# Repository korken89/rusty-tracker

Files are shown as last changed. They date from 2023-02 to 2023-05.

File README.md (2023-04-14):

# Rusty Tracker

**A learning board for LTE-M and tracking technologies**

## Versions

There are 2 versions of the board, based on:

1. uBlox R422-M10S
2. nRF9160 + uBlox M10S GNSS

which can be found in the `master` branch and `nrf` branch respectively.

The two IFA antennas are simulated with Ansys HFSS, files are available.

### uBlox R422-M10S version

This is the main board that development is happening for in the `firmware` folder.

The hardware is tested and working.

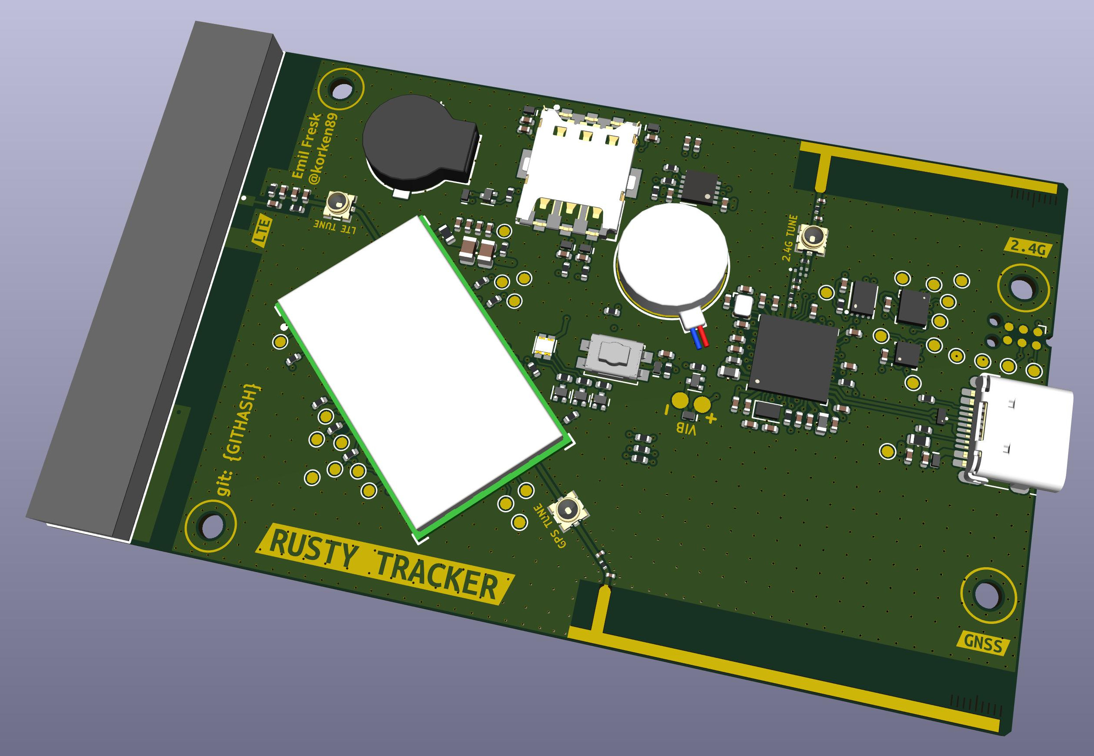
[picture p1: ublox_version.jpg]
ublox uBlox version


### nRF9160 version

This was made as well for learning, not manufactured nor tested.

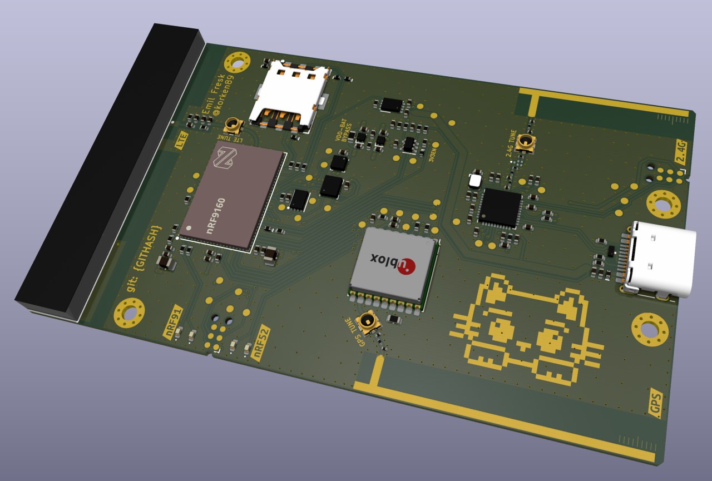
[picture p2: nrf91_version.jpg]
nrf9160 nRf9160 version


## License

This work is licensed under [CERN-OHL-P](cern_ohl_p_v2.txt).

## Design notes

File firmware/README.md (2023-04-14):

# Rusty Tracker Firmware

Firmware for the Rusty Tracker board.

## License

Licensed under either of

- Apache License, Version 2.0 ([LICENSE-APACHE](LICENSE-APACHE) or
  http://www.apache.org/licenses/LICENSE-2.0)

- MIT license ([LICENSE-MIT](LICENSE-MIT) or http://opensource.org/licenses/MIT)

at your option.

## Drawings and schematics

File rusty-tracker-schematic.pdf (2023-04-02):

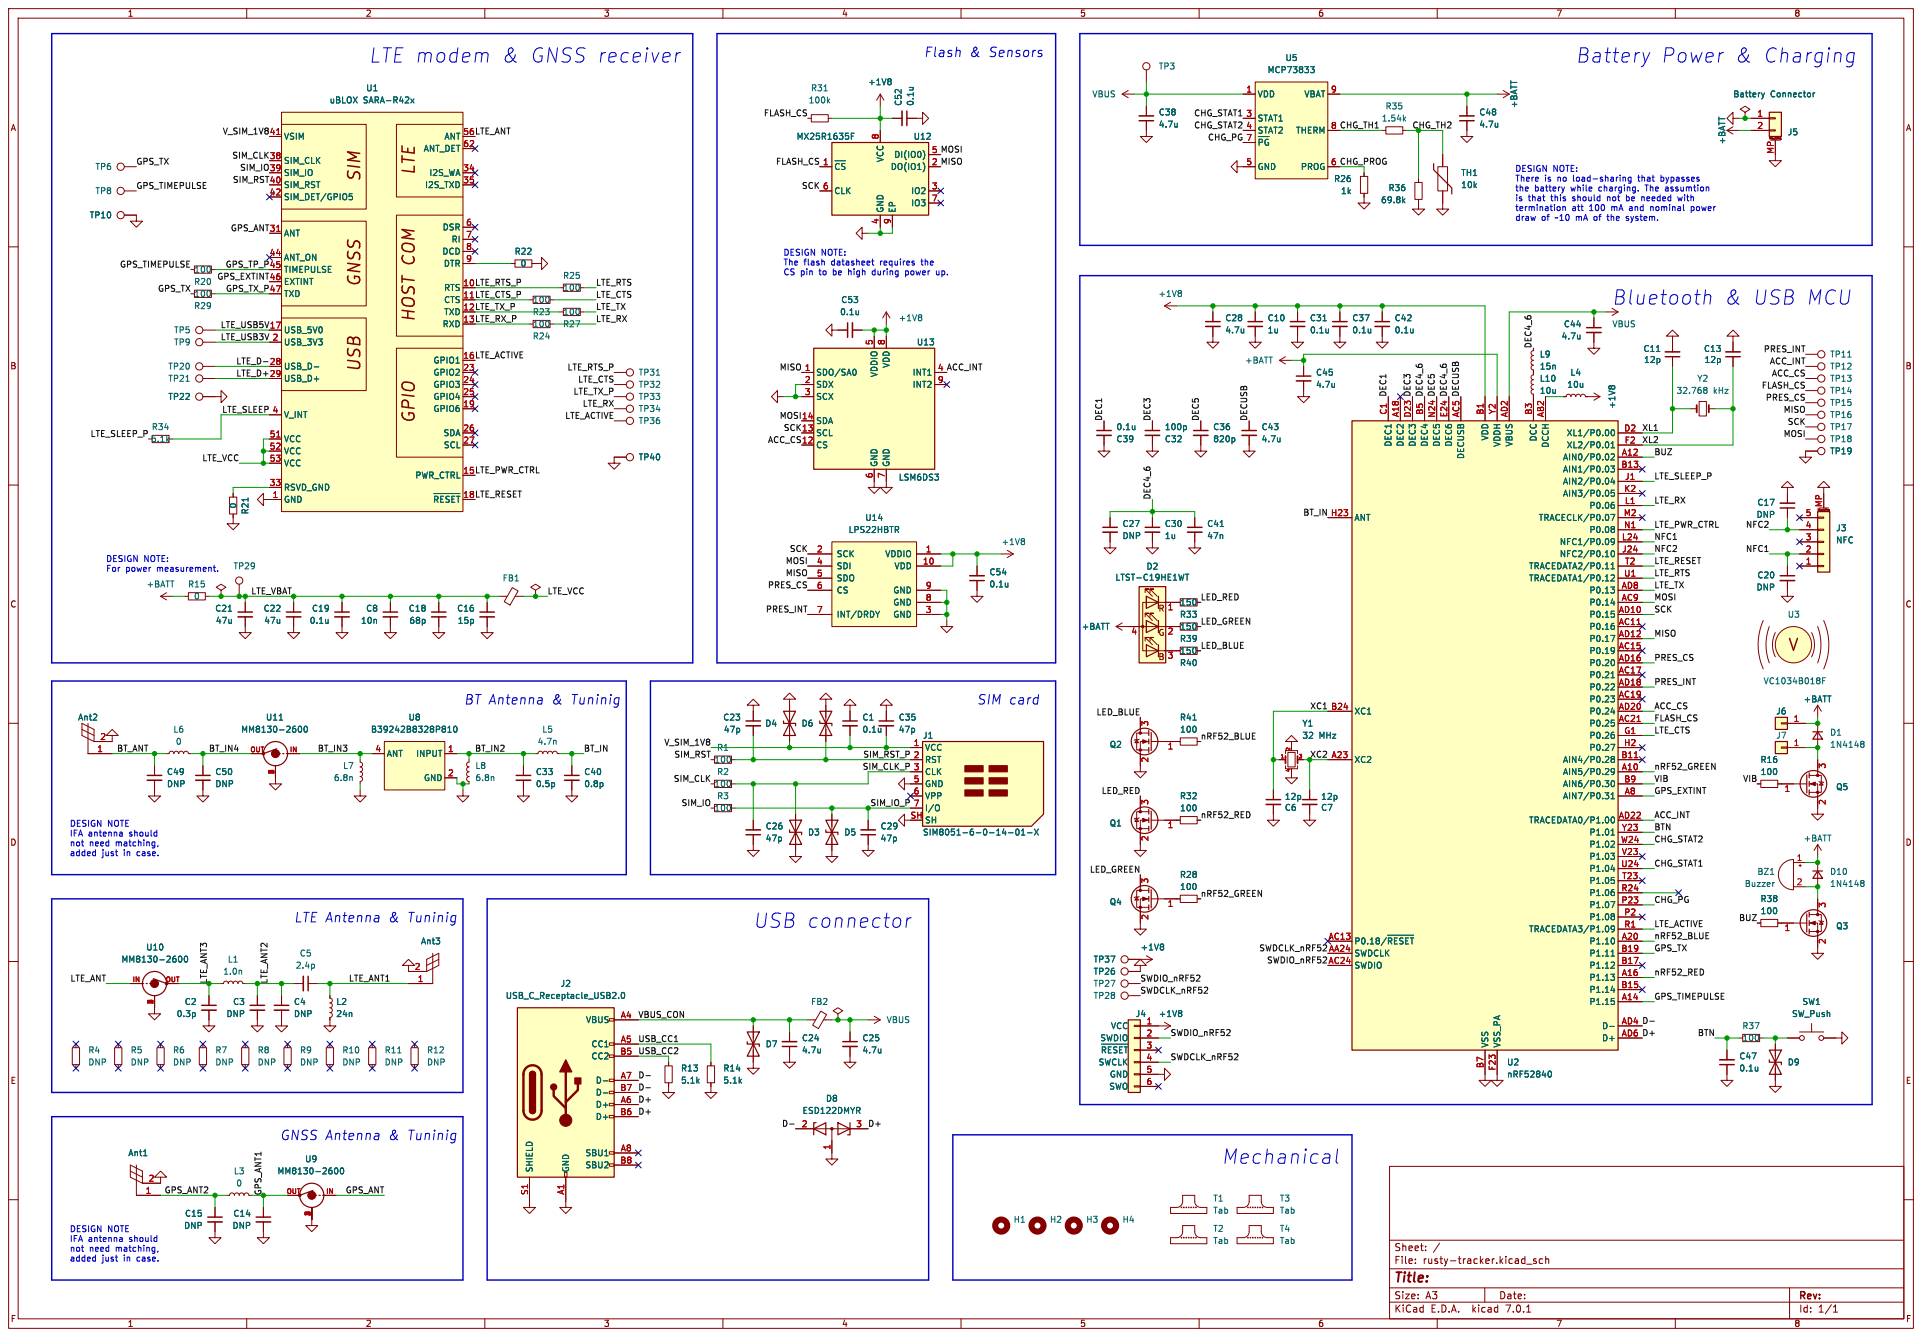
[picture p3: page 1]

LTE modem & GNSS receiver

is that this should not be needed with

SIM card
VCC 1 RST 2 CLK 3 GND 5 VPP 6

INPUT 1 GND 2 ANT 4 C15 DNP

IFA antenna should
not need matching, added just in case.

Id: 1/1 Title: File: rusty-tracker.kicad_sch Sheet: /

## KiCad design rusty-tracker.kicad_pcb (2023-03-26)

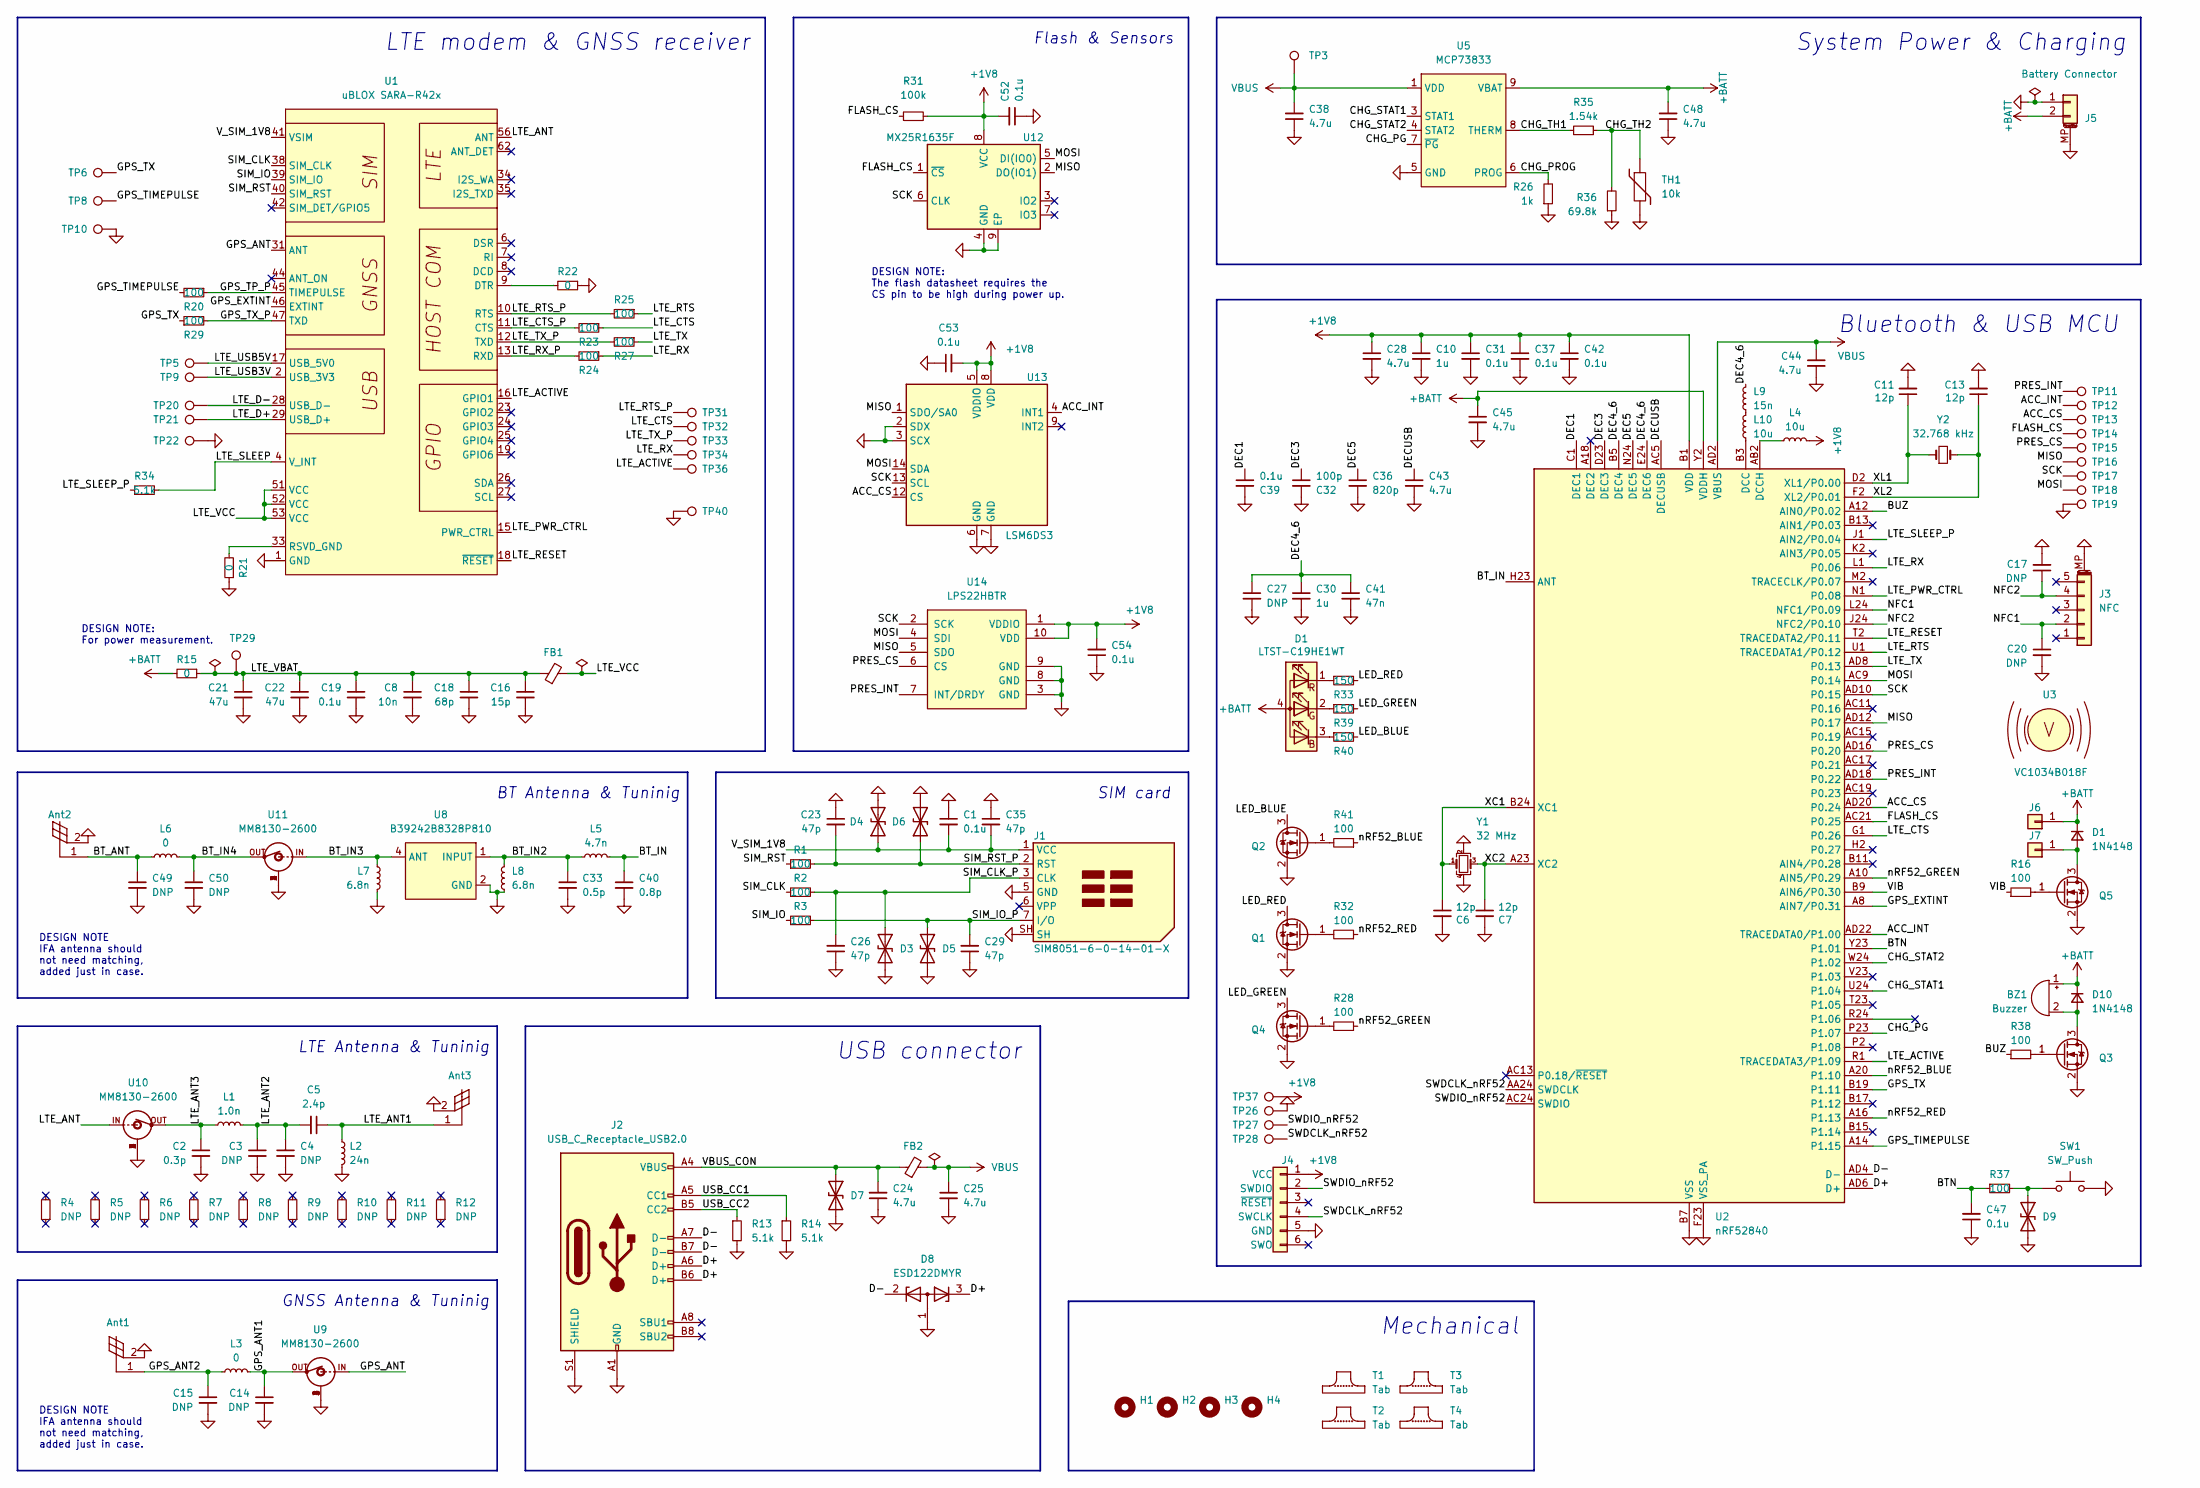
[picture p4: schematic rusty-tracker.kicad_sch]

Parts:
Ant1: antenna; gps-inverted-f
Ant2: antenna; 2.4ghz-inverted-f
Ant3: antenna; P822602
BZ1: Buzzer; AST0927
C1, C19, C31, C37, C39, C42, C47, C52, C53, C54: 0.1u; C_0402
C2: 0.3p; C_0402
C3, C4, C17, C20, C27: DNP; C_0402
C5: 2.4p; C_0402
C6, C7: 12p; C_0402; Tolerance 1%
C8: 10n; C_0402
C10, C30: 1u; C_0402
C11, C13: 12p; C_0402
C14, C15, C49, C50: DNP; C_0201
C16: 15p; C_0402
C18: 68p; C_0402
C21, C22: 47u; C_0805
C23, C26, C29, C35: 47p; C_0402
C24, C25, C28, C38, C43, C44, C45, C48: 4.7u; C_0402
C32: 100p; C_0402
C33: 0.5p; C_0201
C36: 820p; C_0402
C40: 0.8p; C_0201
C41: 47n; C_0402
D1, D10: 1N4148; D_0402_DFN1006
D3, D4, D5, D6, D7, D9: D_TVS; D_0402_DFN1006
D8: ESD122DMYR; X2SON
FB1, FB2: BLM18EG221SN1D; R_0603
H1, H2, H3, H4: MountingHole_Pad; MountingHole_2.2mm_M2
J1: SIM8051-6-0-14-01-X
J2: USB_C_Receptacle_USB2.0; USB_C_Receptacle_USB4105
J3: NFC; TE_0-1734839-5_1x05-1MP_P0.5mm_Horizontal
J4: tag-connect-swd; Tag-Connect_TC2030-IDC-NL_2x03_P1.27mm_Vertical
J5: Battery Connector; JST_SH_SM02B-SRSS-TB_1x02-1MP_P1.00mm_Horizontal
J6, J7: Conn_01x01; pad_circ_1.5mm
L1: 1.0n; R_0402
L2: 24n; R_0402
L3, L6: 0; R_0201
L4, L10: 10u; R_0603
L5: 4.7n; R_0201
L7, L8: 6.8n; R_0201
L9: 15n; R_0402
Q1, Q2, Q3, Q4, Q5: RUM002N02T2L; SOT-723
R1, R2, R3, R16, R20, R23, R24, R25, R27, R28, R29, R32, R37, R38, R41: 100; R_0402
R4, R5, R6, R7, R8, R9, R10, R11, R12: DNP; ANT_0402
R13, R14, R34: 5.1k; R_0402
R15, R21, R22: 0; R_0402
R26: 1k; R_0402
R31: 100k; R_0402
R33, R39, R40: 150; R_0402
R35: 1.54k; R_0402
R36: 69.8k; R_0402
SW1: SW_Push; SW_SPST_EVQP2
T1, T2, T3, T4: Tab
TH1: 10k; R_0402
TP3, TP5, TP6, TP8, TP9, TP10, TP11, TP12, TP13, TP14, TP15, TP16, TP17, TP18, TP19, TP20, TP21, TP22, TP26, TP27, TP28, TP29, TP31, TP32, TP33, TP34, TP36, TP37, TP40: TestPoint; TestPoint_Pad_D1.0mm
U1: uBLOX SARA-R42x; u-blox SARA-R4
U2: nRF52840; Nordic_AQFN-73-1EP_7x7mm_P0.5mm
U3: VC1034B018F
U5: MCP73833; DFN-10-1EP_3x3mm_P0.5mm_EP1.55x2.48mm
U8: B39242B8328P810
U9, U10, U11: MM8130-2600
U12: MX25R1635F; USON-8-3x2mm-EP
U13: LSM6DS3; LGA-14_3x2.5mm_P0.5mm_LayoutBorder3x4y
U14: LPS22HBTR; ST_HLGA-10_2x2mm_P0.5mm_LayoutBorder3x2y
Y1: 32 MHz; Crystal_4Pin_2.0x1.6mm
Y2: 32.768 kHz; Crystal_SMD_2012-2Pin_2.0x1.2mm

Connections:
+1V8: C10.1, C28.1, C31.1, C37.1, C42.1, C52.2, C53.2, C54.2, J4.1 (VCC), L4.1, R31.2, TP37.1, U2.A22 (VDD), U2.AD14 (VDD), U2.AD23 (VDD), U2.B1 (VDD), U2.W1 (VDD), U12.8 (VCC), U13.5 (VDDIO), U13.8 (VDD), U14.1 (VDDIO), U14.10 (VDD)
/ACC_CS: TP13.1, U2.AD20 (P0.24), U13.12 (CS)
/ACC_INT: TP12.1, U2.AD22 (TRACEDATA0/P1.00), U13.4 (INT1)
/BTN: C47.2, R37.1, U2.Y23 (P1.01)
/BT_ANT: Ant2.1, C49.1, L6.2
/BT_IN: C40.1, L5.1, U2.H23 (ANT)
/BT_IN2: C33.1, L5.2, L8.1, U8.1 (INPUT)
/BT_IN3: L7.2, U8.4 (ANT), U11.IN
/BT_IN4: C50.1, L6.1, U11.OUT
/BUZ: R38.1, U2.A12 (AIN0/P0.02)
/CHG_PG: U2.P23 (P1.07), U5.7 (~PG)
/CHG_PROG: R26.2, U5.6 (PROG)
/CHG_STAT1: U2.U24 (P1.04), U5.3 (STAT1)
/CHG_STAT2: U2.W24 (P1.02), U5.4 (STAT2)
/CHG_TH1: R35.2, U5.8 (THERM)
/CHG_TH2: R35.1, R36.2, TH1.1
/D+: D8.3 (K), J2.A6 (D+), J2.B6 (D+), U2.AD6 (D+)
/D-: D8.2 (K), J2.A7 (D-), J2.B7 (D-), U2.AD4 (D-)
/DEC1: C39.1, U2.C1 (DEC1)
/DEC3: C32.1, U2.D23 (DEC3)
/DEC4_6: C27.1, C30.1, C41.1, L9.1, U2.B5 (DEC4), U2.E24 (DEC6)
/DEC5: C36.1, U2.N24 (DEC5)
/DECUSB: C43.1, U2.AC5 (DECUSB)
/FLASH_CS: R31.1, TP14.1, U2.AC21 (P0.25), U12.1 (~CS)
/GPS_ANT: U1.31 (ANT), U9.IN
/GPS_ANT1: C14.1, L3.2, U9.OUT
/GPS_ANT2: Ant1.1, C15.1, L3.1
/GPS_EXTINT: U1.46 (EXTINT), U2.A8 (AIN7/P0.31)
/GPS_TIMEPULSE: R20.2, TP8.1, U2.A14 (P1.15)
/GPS_TP_P: R20.1, U1.45 (TIMEPULSE)
/GPS_TX: R29.1, TP6.1, U2.B19 (P1.11)
/GPS_TX_P: R29.2, U1.47 (TXD)
/LED_BLUE: Q2.3 (D), R40.2
/LED_GREEN: Q4.3 (D), R39.2
/LED_RED: Q1.3 (D), R33.2
/LTE_ACTIVE: TP36.1, U1.16 (GPIO1), U2.R1 (TRACEDATA3/P1.09)
/LTE_ANT: U1.56 (ANT), U10.IN
/LTE_ANT1: Ant3.1, C5.1, L2.1
/LTE_ANT2: C3.1, C4.1, C5.2, L1.2
/LTE_ANT3: C2.1, L1.1, U10.OUT
/LTE_CTS: R23.1, TP32.1, U2.G1 (P0.26)
/LTE_CTS_P: R23.2, U1.11 (CTS)
/LTE_D+: TP21.1, U1.29 (USB_D+)
/LTE_D-: TP20.1, U1.28 (USB_D-)
/LTE_PWR_CTRL: U1.15 (PWR_CTRL), U2.N1 (P0.08)
/LTE_RESET: U1.18 (~RESET), U2.T2 (TRACEDATA2/P0.11)
/LTE_RTS: R25.1, U2.U1 (TRACEDATA1/P0.12)
/LTE_RTS_P: R25.2, TP31.1, U1.10 (RTS)
/LTE_RX: R24.1, TP34.1, U2.L1 (P0.06)
/LTE_RX_P: R24.2, U1.13 (RXD)
/LTE_SLEEP: R34.2, U1.4 (V_INT)
/LTE_SLEEP_P: R34.1, U2.J1 (AIN2/P0.04)
/LTE_TX: R27.1, U2.AD8 (P0.13)
/LTE_TX_P: R27.2, TP33.1, U1.12 (TXD)
/LTE_USB3V: TP9.1, U1.2 (USB_3V3)
/LTE_USB5V: TP5.1, U1.17 (USB_5V0)
/LTE_VBAT: C8.1, C16.1, C18.1, C19.1, C21.1, C22.1, FB1.1, R15.1, TP29.1
/LTE_VCC: FB1.2, U1.51 (VCC), U1.52 (VCC), U1.53 (VCC)
/MISO: TP16.1, U2.AD12 (P0.17), U12.2 (DO(IO1)), U13.1 (SDO/SA0), U14.5 (SDO)
/MOSI: TP18.1, U2.AC9 (P0.14), U12.5 (DI(IO0)), U13.14 (SDA), U14.4 (SDI)
/NFC1: C20.1, J3.2, U2.L24 (NFC1/P0.09)
/NFC2: C17.1, J3.4, U2.J24 (NFC2/P0.10)
/PRES_CS: TP15.1, U2.AD16 (P0.20), U14.6 (CS)
/PRES_INT: TP11.1, U2.AD18 (P0.22), U14.7 (INT/DRDY)
/SCK: TP17.1, U2.AD10 (P0.15), U12.6 (CLK), U13.13 (SCL), U14.2 (SCK)
/SIM_CLK: R2.1, U1.38 (SIM_CLK)
/SIM_CLK_P: C26.2, D3.1 (A1), J1.3 (CLK), R2.2
/SIM_IO: R3.1, U1.39 (SIM_IO)
/SIM_IO_P: C29.2, D5.1 (A1), J1.7 (I/O), R3.2
/SIM_RST: R1.1, U1.40 (SIM_RST)
/SIM_RST_P: C23.2, D6.1 (A1), J1.2 (RST), R1.2
/SWDCLK_nRF52: J4.4 (SWCLK), TP28.1, U2.AA24 (SWDCLK)
/SWDIO_nRF52: J4.2 (SWDIO), TP27.1, U2.AC24 (SWDIO)
/USB_CC1: J2.A5 (CC1), R14.1
/USB_CC2: J2.B5 (CC2), R13.1
/VBUS_CON: C24.2, D7.1 (A1), FB2.1, J2.A4 (VBUS), J2.A9 (VBUS), J2.B4 (VBUS), J2.B9 (VBUS)
/VIB: R16.1, U2.B9 (AIN6/P0.30)
/V_SIM_1V8: C1.2, C35.2, D4.1 (A1), J1.1 (VCC), U1.41 (VSIM)
/XC1: C6.1, U2.B24 (XC1), Y1.1
/XC2: C7.1, U2.A23 (XC2), Y1.3
/XL1: C11.1, U2.D2 (XL1/P0.00), Y2.1
/XL2: C13.1, U2.F2 (XL2/P0.01), Y2.2
/nRF52_BLUE: R41.1, U2.A20 (P1.10)
/nRF52_GREEN: R28.1, U2.A10 (AIN5/P0.29)
/nRF52_RED: R32.1, U2.A16 (P1.13)
GND: Ant1.2, Ant2.2, Ant3.2, C1.1, C2.2, C3.2, C4.2, C6.2, C7.2, C8.2, C10.2, C11.2, C13.2, C14.2, C15.2, C16.2, C17.2, C18.2, C19.2, C20.2, C21.2, C22.2, C23.1, C24.1, C25.2, C26.1, C27.2, C28.2, C29.1, C30.2, C31.2, C32.2, C33.2, C35.1, C36.2, C37.2, C38.1, C39.2, C40.2, C41.2, C42.2, C43.2, C44.2, C45.2, C47.1, C48.1, C49.2, C50.2, C52.1, C53.1, C54.1, D3.2 (A2), D4.2 (A2), D5.2 (A2), D6.2 (A2), D7.2 (A2), D8.1 (A), D9.2 (A2), J1.5 (GND), J1.SH, J2.A1 (GND), J2.A12 (GND), J2.B1 (GND), J2.B12 (GND), J2.S1 (SHIELD), J3.MP (MountPin), J4.5 (GND), J5.1, J5.MP (MountPin), L2.2, L7.1, L8.2, Q1.2 (S), Q2.2 (S), Q3.2 (S), Q4.2 (S), Q5.2 (S), R13.2, R14.2, R21.1, R22.1, R26.1, R36.1, SW1.2, TH1.2, TP10.1, TP19.1, TP22.1, TP26.1, TP40.1, U1.1 (GND), U1.3 (GND), U1.5 (GND), U1.14 (GND), U1.20 (GND), U1.21 (GND), U1.22 (GND), U1.30 (GND), U1.32 (GND), U1.43 (GND), U1.50 (GND), U1.54 (GND), U1.55 (GND), U1.57 (GND), U1.58 (GND), U1.59 (GND), U1.60 (GND), U1.61 (GND), U1.63 (GND), U1.64 (GND), U1.65 (GND), U1.66 (GND), U1.67 (GND), U1.68 (GND), U1.69 (GND), U1.70 (GND), U1.71 (GND), U1.72 (GND), U1.73 (GND), U1.74 (GND), U1.75 (GND), U1.76 (GND), U1.77 (GND), U1.78 (GND), U1.79 (GND), U1.80 (GND), U1.81 (GND), U1.82 (GND), U1.83 (GND), U1.84 (GND), U1.85 (GND), U1.86 (GND), U1.87 (GND), U1.88 (GND), U1.89 (GND), U1.90 (GND), U1.91 (GND), U1.92 (GND), U1.93 (GND), U1.94 (GND), U1.95 (GND), U1.96 (GND), U2.B7 (VSS), U2.EP (VSS), U2.F23 (VSS_PA), U5.5 (GND), U5.11 (PAD), U8.2 (GND), U8.3 (GND), U8.5 (GND), U9.1, U9.2, U9.3, U9.4, U10.1, U10.2, U10.3, U10.4, U11.1, U11.2, U11.3, U11.4, U12.4 (GND), U12.9 (EP), U13.2 (SDX), U13.3 (SCX), U13.6 (GND), U13.7 (GND), U14.3 (GND), U14.8 (GND), U14.9 (GND), Y1.2, Y1.4
unnamed: BZ1.2 (+), D10.2 (A), Q3.3 (D)
unnamed: D9.1 (A1), R37.2, SW1.1
unnamed: L9.2, L10.1
unnamed: Q1.1 (G), R32.2
unnamed: Q2.1 (G), R41.2
unnamed: Q3.1 (G), R38.2
unnamed: Q4.1 (G), R28.2
unnamed: Q5.1 (G), R16.2
unnamed: R22.2, U1.9 (DTR)
unnamed: R21.2, U1.33 (RSVD_GND)
unnamed: L10.2, U2.B3 (DCC)
unnamed: L4.2, U2.AB2 (DCCH)
VBUS: C25.1, C38.2, C44.1, FB2.2, TP3.1, U2.AD2 (VBUS), U5.1 (VDD), U5.2 (VDD)

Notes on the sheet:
DESIGN NOTE IFA antenna should not need matching, added just in case.
GNSS Antenna & Tuninig
System Power & Charging
LTE modem & GNSS receiver
SIM card
LTE Antenna & Tuninig
DESIGN NOTE: The flash datasheet requires the CS pin to be high during power up.
BT Antenna & Tuninig
DESIGN NOTE: For power measurement.
Bluetooth & USB MCU
USB connector
Mechanical
Flash & Sensors

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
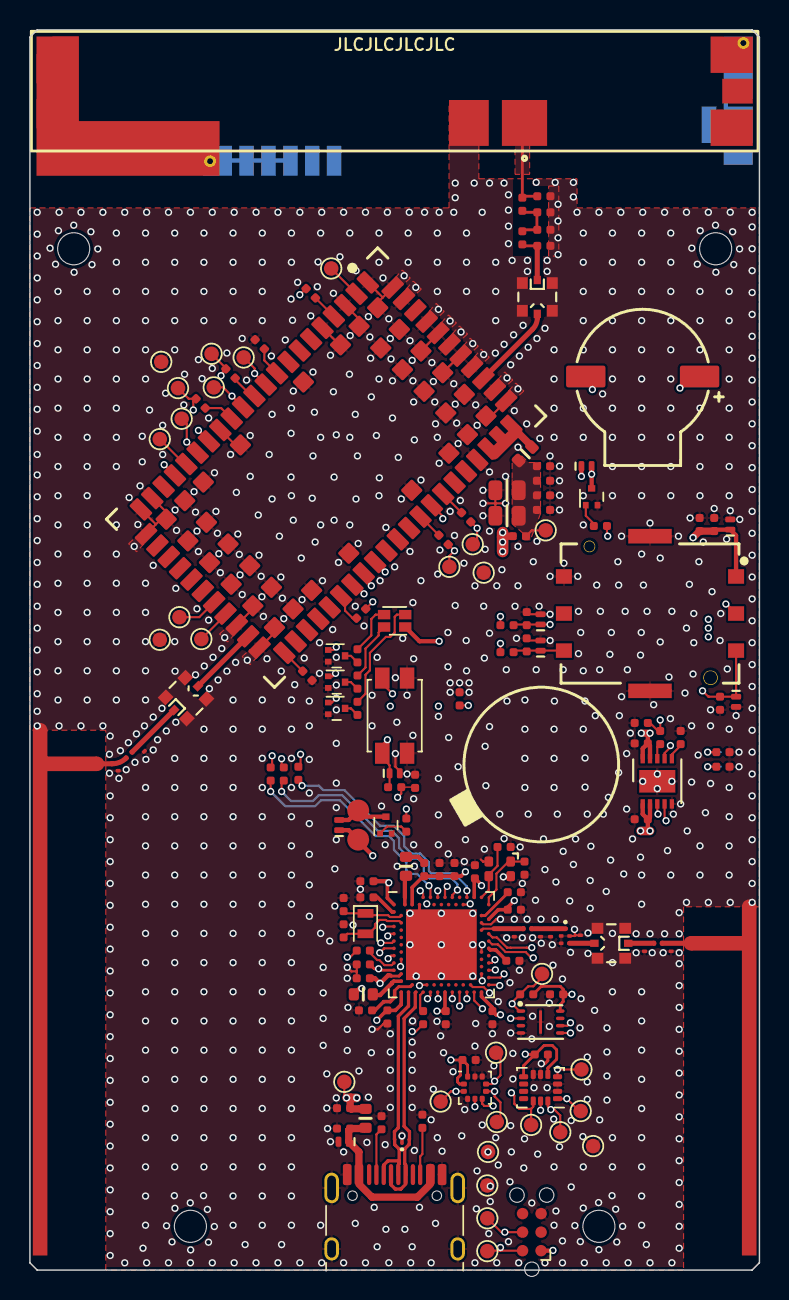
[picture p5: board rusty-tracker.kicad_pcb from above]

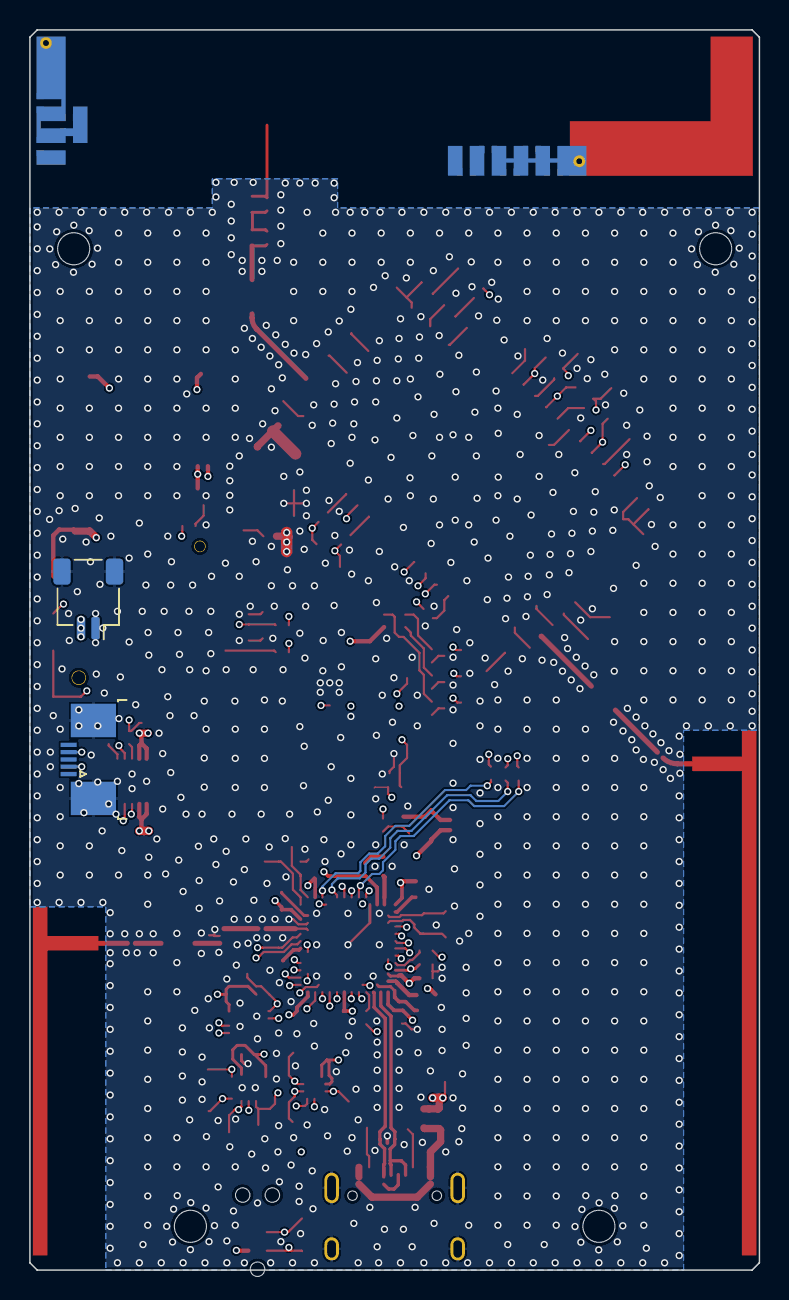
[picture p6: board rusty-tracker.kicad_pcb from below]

Board: 6 copper layers, 50.0 x 85.0 mm, 181 parts (12 on the bottom side), 104 nets.

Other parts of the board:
D2: LTST-C19HE1WT; LED_LiteOn_LTST-C19HE1WT
kibuzzard-63E4FB2E: G***; kibuzzard-63E4FB2E
kibuzzard-63E4FB20: G***; kibuzzard-63E4FB20
kibuzzard-63E50121: G***; kibuzzard-63E50121
kibuzzard-63FA6CC8: G***; kibuzzard-63FA6CC8
kibuzzard-63FA0532: G***; kibuzzard-63FA0532

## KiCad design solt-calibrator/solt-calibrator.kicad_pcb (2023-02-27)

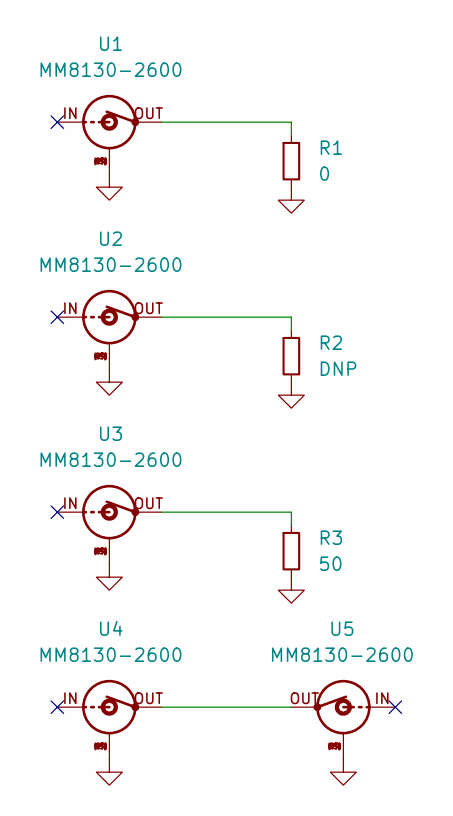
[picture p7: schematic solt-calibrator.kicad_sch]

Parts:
R1: 0; R_0603_1608Metric
R2: DNP; R_0603_1608Metric
R3: 50; R_0603_1608Metric
U1, U2, U3, U4, U5: MM8130-2600

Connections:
GND: R1.2, R2.2, R3.2, U1.1, U1.2, U1.3, U1.4, U2.1, U2.2, U2.3, U2.4, U3.1, U3.2, U3.3, U3.4, U4.1, U4.2, U4.3, U4.4, U5.1, U5.2, U5.3, U5.4
unnamed: R1.1, U1.OUT
unnamed: R2.1, U2.OUT
unnamed: R3.1, U3.OUT
unnamed: U4.OUT, U5.OUT

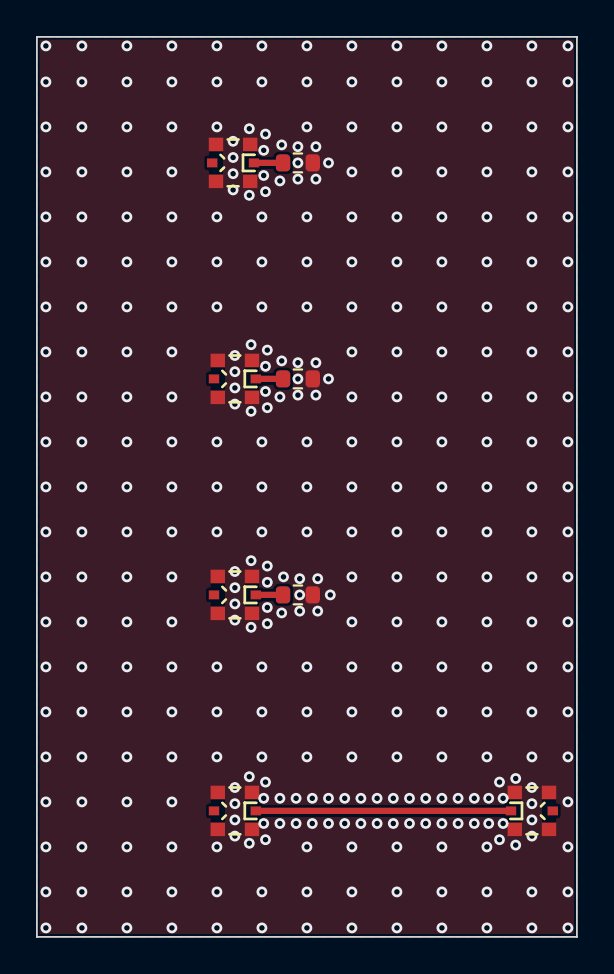
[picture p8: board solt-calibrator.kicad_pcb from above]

Board: 4 copper layers, 30.0 x 50.0 mm, 8 parts (0 on the bottom side), 5 nets.

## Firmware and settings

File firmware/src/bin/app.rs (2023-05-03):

#![no_main]
#![no_std]
#![feature(type_alias_impl_trait)]
#![feature(async_fn_in_trait)]
#![allow(incomplete_features)]

use rtic_monotonics::{nrf::timer::fugit::MicrosDurationU32, systick::Systick, Monotonic};
use rusty_tracker as _; // global logger + panicking-behavior + memory layout

pub mod tasks;

defmt::timestamp!("{=u64:us}", {
    let time_us: MicrosDurationU32 = Systick::now().duration_since_epoch().convert();

    time_us.ticks() as u64
});

pub mod pac {
    // pub use cortex_m_rt::interrupt;
    pub use embassy_nrf::pac::Interrupt as interrupt;
    pub use embassy_nrf::pac::*;
}

#[rtic::app(device = crate::pac, dispatchers = [SWI0_EGU0], peripherals = false)]
mod app {
    use crate::tasks::*;
    use rusty_tracker::bsp::{BoardLeds, ChargerStatus, LteComponents, Voltages};

    #[shared]
    struct Shared {}

    #[local]
    struct Local {}

    #[init]
    fn init(cx: init::Context) -> (Shared, Local) {
        defmt::info!("pre init");

        let (leds, voltages, charger_status, lte_components) = rusty_tracker::bsp::init(cx.core);

        led_control::spawn(leds, voltages, charger_status).ok();
        modem_worker::spawn(lte_components).ok();
        modem_test::spawn().ok();

        (Shared {}, Local {})
    }

    extern "Rust" {
        #[task]
        async fn modem_test(_: modem_test::Context);

        #[task]
        async fn modem_worker(_: modem_worker::Context, lte_components: LteComponents);

        #[task]
        async fn led_control(
            _: led_control::Context,
            leds: BoardLeds,
            voltages: Voltages,
            charger_status: ChargerStatus,
        );
    }

    // #[task]
    // async fn modem_talker(
    //     _: modem_talker::Context,
    //     lte_on: Input<'static, P0_04>,
    //     mut lte_pwr: Output<'static, P0_08>,
    //     mut tx: UarteTx<'static, UARTE0>,
    // ) {
    //     'outer: loop {
    //         defmt::println!("Trying to start LTE modem");
    //         lte_pwr.set_low();
    //         Systick::delay(500.millis()).await;
    //         lte_pwr.set_high();

    //         for _ in 0..10 {
    //             if lte_on.is_high() {
    //                 defmt::println!("LTE modem started!");
    //                 break 'outer;
    //             }
    //             Systick::delay(500.millis()).await;
    //         }
    //     }

    //     defmt::println!("Sending: ATI");
    //     tx.write(b"ATI\r\n").await.unwrap(); // Module name
    //     Systick::delay(100.millis()).await;

    //     defmt::println!("Sending: AT+CIMI");
    //     tx.write(b"AT+CIMI\r\n").await.unwrap(); // IMSI
    //     Systick::delay(100.millis()).await;

    //     defmt::println!("Sending: AT+CGSN");
    //     tx.write(b"AT+CGSN\r\n").await.unwrap(); // IMEI
    //     Systick::delay(100.millis()).await;

    //     defmt::println!("Sending: AT+URAT?");
    //     tx.write(b"AT+URAT?\r\n").await.unwrap();
    //     Systick::delay(100.millis()).await;

    //     // tx.write(b"AT+UBANDMASK?\r\n").await.unwrap(); // IMEI
    //     // Systick::delay(100.millis()).await;
    //     // tx.write(b"AT+UMNOPROF?\r\n").await.unwrap(); // IMEI
    //     // Systick::delay(100.millis()).await;
    //     // defmt::println!("Sending APN");
    //     //     tx.write(b"AT+UPSD=0,1,\"iot.1nce.net\"\r\n").await.unwrap(); // IMEI
    //     // Systick::delay(100.millis()).await;
    //     // tx.write(b"AT+UPSD=0\r\n").await.unwrap(); // IMEI
    //     // Systick::delay(100.millis()).await;

    //     defmt::println!("Sending DNS");
    //     tx.write(b"AT+UDNSRN=0,\"one.one.one.one\"\r\n")
    //         .await
    //         .unwrap(); // IMEI

    //     Systick::delay(3000.millis()).await;

    //     // // tx.write(b"AT+CSQ?\r\n").await.unwrap(); // IMEI
    //     // tx.write(b"AT+UCFSCAN=7\r\n").await.unwrap(); // IMEI

    //     defmt::println!("Sending: AT+USOCR=6");
    //     tx.write(b"AT+USOCR=6\r\n").await.unwrap();
    //     Systick::delay(100.millis()).await;

    //     defmt::println!("Sending: AT+USOCO=0,\"79.136.27.216\",5684");
    //     tx.write(b"AT+USOCO=0,\"79.136.27.216\",5684\r\n")
    //         .await
    //         .unwrap();
    //     Systick::delay(100.millis()).await;

    //     loop {
    //         defmt::println!("Sending: AT+USOWR=0,12,\"Hello world!\"");
    //         tx.write(b"AT+USOWR=0,12,\"Hello world!\"\r\n")
    //             .await
    //             .unwrap();
    //         Systick::delay(100.millis()).await;

    //         // Read how many bytes on socket
    //         defmt::println!("Sending: AT+USORD=0,0");
    //         tx.write(b"AT+USORD=0,0\r\n").await.unwrap();
    //         Systick::delay(1_000.millis()).await;
    //     }
    // }

    // #[task]
    // async fn modem_listener(
    //     _: modem_listener::Context,
    //     mut rx: UarteRxWithIdle<'static, UARTE0, TIMER0>,
    // ) {
    //     let mut buf = [0; 1024];
    //     loop {
    //         let r = rx.read_until_idle(&mut buf).await.unwrap();
    //         defmt::println!(
    //             "Received {} bytes: {}\n{}",
    //             r,
    //             &buf[..r],
    //             core::str::from_utf8(&buf[..r]).unwrap()
    //         );
    //         // Systick::delay(100.millis()).await;
    //     }
    // }

    // #[task]
    // async fn led_control(
    //     _: led_control::Context,
    //     mut leds: SimplePwm<'static, PWM0>, // leds: BoardLeds,
    //                                         // voltages: Voltages,
    //                                         // charger_status: ChargerStatus,
    // ) {
    //     // rusty_tracker::tasks::led_control(leds, voltages, charger_status).await;
    //     loop {
    //         leds.enable();
    //         // defmt::println!("...");
    //         leds.set_duty(0, 990);
    //         leds.set_duty(1, 1000);
    //         leds.set_duty(2, 1000);
    //         Systick::delay(200.millis()).await;

    //         leds.set_duty(0, 1000);
    //         leds.set_duty(1, 990);
    //         leds.set_duty(2, 1000);
    //         Systick::delay(200.millis()).await;

    //         leds.set_duty(0, 1000);
    //         leds.set_duty(1, 1000);
    //         leds.set_duty(2, 990);
    //         Systick::delay(200.millis()).await;

    //         leds.set_duty(0, 1000);
    //         leds.set_duty(1, 1000);
    //         leds.set_duty(2, 1000);
    //         leds.disable();
    //         Systick::delay(1000.millis()).await;
    //     }
    // }
}

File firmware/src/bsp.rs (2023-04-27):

use embassy_nrf::{
    config::HfclkSource,
    gpio::{Input, Level, Output, OutputDrive, Pull},
    peripherals::{P0_04, P0_08, P0_11, P1_02, P1_04, P1_07, PWM0, TIMER0, UARTE0},
    pwm::{Prescaler, SimplePwm},
    saadc::Saadc,
    uarte::{UarteRxWithIdle, UarteTx},
    {bind_interrupts, saadc, uarte},
};
use rtic_monotonics::systick::Systick;

use crate::sara_r4xx::{AsyncReadUntilIdle, AsyncWriter, IoControl};

pub struct BoardLeds {
    pwm: SimplePwm<'static, PWM0>,
}

impl BoardLeds {
    pub fn levels(&mut self, red: f32, green: f32, blue: f32) {
        let max_duty = 1000;

        if red > 0. || green > 0. || blue > 0. {
            let red_level = red.min(1.).max(0.) * max_duty as f32 + 0.5;
            let green_level = green.min(1.).max(0.) * max_duty as f32 + 0.5;
            let blue_level = blue.min(1.).max(0.) * max_duty as f32 + 0.5;

            self.pwm.enable();
            self.pwm.set_duty(0, max_duty - red_level as u16);
            self.pwm.set_duty(1, max_duty - green_level as u16);
            self.pwm.set_duty(2, max_duty - blue_level as u16);
        } else {
            self.pwm.disable();
        }
    }
}

pub struct Voltages {
    adc: Saadc<'static, 1>,
}

impl Voltages {
    pub async fn measure_vbat(&mut self) -> f32 {
        let mut buf = [0; 1];
        self.adc.sample(&mut buf).await;

        (buf[0] as f32 / ((1 << 12) as f32 * (5. / 12.))) * 5.
    }
}

pub struct ChargerStatus {
    pg: Input<'static, P1_07>,
    stat1: Input<'static, P1_04>,
    stat2: Input<'static, P1_02>,
}

#[derive(Copy, Clone, Debug, PartialEq, Eq, defmt::Format, Hash)]
pub enum ChargingStatus {
    /// There is no cable connected.
    No5V,
    /// The charger is powered, but not charging.
    Standby,
    /// The battery is charging.
    Charging,
    // The charging has finished.
    ChargeComplete,
}

impl ChargerStatus {
    pub fn usb_connected(&self) -> bool {
        self.pg.is_low()
    }

    //
    pub fn status(&self) -> ChargingStatus {
        if !self.usb_connected() {
            return ChargingStatus::No5V;
        }

        let (stat1_low, stat2_low) = (self.stat1.is_low(), self.stat2.is_low());

        match (stat1_low, stat2_low) {
            (true, true) => ChargingStatus::Standby, // System test mode
            (true, false) => ChargingStatus::Charging,
            (false, true) => ChargingStatus::ChargeComplete,
            (false, false) => ChargingStatus::Standby,
        }
    }
}

pub struct UTx {
    pub tx: UarteTx<'static, UARTE0>,
}

impl AsyncWriter for UTx {
    async fn write(&mut self, buf: &[u8]) {
        self.tx.write(buf).await.expect("ICE: Write")
    }
}

pub struct URx {
    pub rx: UarteRxWithIdle<'static, UARTE0, TIMER0>,
}

impl AsyncReadUntilIdle for URx {
    async fn read_until_idle(&mut self, buf: &mut [u8]) -> usize {
        self.rx.read_until_idle(buf).await.expect("ICE: Read")
    }
}

pub struct LteComponents {
    pub io_interface:
        IoControl<Output<'static, P0_08>, Input<'static, P0_04>, Output<'static, P0_11>, Systick>,
    pub tx: UTx,
    pub rx: URx,
}

bind_interrupts!(struct Irqs {
    UARTE0_UART0 => uarte::InterruptHandler<UARTE0>;
    SAADC => saadc::InterruptHandler;
});

#[inline(always)]
pub fn init(c: cortex_m::Peripherals) -> (BoardLeds, Voltages, ChargerStatus, LteComponents) {
    let mut config = embassy_nrf::config::Config::default();
    config.hfclk_source = HfclkSource::ExternalXtal;
    config.dcdc.reg0 = true;
    config.dcdc.reg1 = true;
    let p = embassy_nrf::init(config);

    //
    // Disable vibrator and buzzer
    //
    let vib = Output::new(p.P0_30, Level::Low, OutputDrive::Standard);
    core::mem::forget(vib);
    let buz = Output::new(p.P0_02, Level::Low, OutputDrive::Standard);
    core::mem::forget(buz);

    //
    // Battery measurement
    //
    let mut config = saadc::Config::default();
    config.resolution = saadc::Resolution::_12BIT;
    let mut channel_config = saadc::ChannelConfig::single_ended(saadc::VddhDiv5Input);
    channel_config.time = saadc::Time::_40US;
    channel_config.gain = saadc::Gain::GAIN1_4;
    let saadc = Saadc::new(p.SAADC, Irqs, config, [channel_config]);

    let voltages = Voltages { adc: saadc };

    //
    // Setup LED PWM
    //
    let red = p.P1_13;
    let green = p.P0_29;
    let blue = p.P1_10;

    let mut pwm = SimplePwm::new_3ch(p.PWM0, red, green, blue);

    pwm.set_prescaler(Prescaler::Div1);
    pwm.set_max_duty(1000);

    pwm.set_duty(0, 1000);
    pwm.set_duty(1, 1000);
    pwm.set_duty(2, 1000);

    let leds = BoardLeds { pwm };

    //
    // Charger
    //

    let pg = Input::new(p.P1_07, Pull::Up);
    let stat1 = Input::new(p.P1_04, Pull::Up);
    let stat2 = Input::new(p.P1_02, Pull::Up);
    let charger_status = ChargerStatus { pg, stat1, stat2 };

    //
    // Button
    //

    //
    // LTE modem connections
    //
    let mut config = uarte::Config::default();
    config.parity = uarte::Parity::EXCLUDED;
    config.baudrate = uarte::Baudrate::BAUD115200;

    let uart = uarte::Uarte::new_with_rtscts(
        p.UARTE0, Irqs,    // ..
        p.P0_06, // TX
        p.P0_13, // RX
        p.P0_26, // CTS
        p.P0_12, // RTS
        config,
    );
    let (tx, rx) = uart.split_with_idle(p.TIMER0, p.PPI_CH0, p.PPI_CH1);

    let lte_reset = Output::new(p.P0_11, Level::High, OutputDrive::Standard0Disconnect1);
    let lte_on = Input::new(p.P0_04, Pull::None);

    // LTE Power needs to be open drain
    let lte_pwr = Output::new(p.P0_08, Level::High, OutputDrive::Standard0Disconnect1);

    let io_interface = IoControl {
        pwr_ctrl: lte_pwr,
        v_int: lte_on,
        reset: lte_reset,
        delay: Systick {},
    };
    let lte_components = LteComponents {
        io_interface,
        tx: UTx { tx },
        rx: URx { rx },
    };

    defmt::info!("uarte initialized!");

    //
    // GPS connections
    //

    let systick_token = rtic_monotonics::create_systick_token!();
    Systick::start(c.SYST, 64_000_000, systick_token);
    defmt::info!("init done");

    (leds, voltages, charger_status, lte_components)
}

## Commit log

2023-02-27 Rusty Tracker - uBlox version
    [rusty-tracker.kicad_pcb, rusty-tracker.kicad_sch, solt-calibrator.kicad_pcb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]
2023-02-27 Add support for VBAT -> VDDH, and DCDC for the nRF52840
    [rusty-tracker.kicad_pcb, rusty-tracker.kicad_sch]
2023-02-28 Add protection & debounce to button
    [rusty-tracker.kicad_pcb, rusty-tracker.kicad_sch]
2023-03-01 Make LDO DNP
    [rusty-tracker.kicad_pcb, rusty-tracker.kicad_sch]
2023-03-02 Remove GND connection in screws
    [rusty-tracker.kicad_pcb, rusty-tracker.kicad_sch]
2023-03-02 Fix antenna feed and ground
    [rusty-tracker.kicad_pcb]
2023-03-12 KiCAD v7, 6 layer version
    [rusty-tracker.kicad_pcb]
2023-03-15 Added buzzer
    [rusty-tracker.kicad_pcb, rusty-tracker.kicad_sch]
2023-03-22 Updated with buzzer and vibrator, removed voltage dividers
    As they are available in the nRF52840 and charging IC
    [rusty-tracker.kicad_pcb, rusty-tracker.kicad_sch]
2023-03-22 Order sent to JLCPCB
    [rusty-tracker.kicad_pcb, rusty-tracker.kicad_sch]
2023-03-25 Nicer text
    [rusty-tracker.kicad_pcb]
2023-03-26 Update via to 0.3/0.5 mm to work with new JLCPCB 6L service without extra cost
    [rusty-tracker.kicad_pcb]
2023-03-26 Moved firmware to master, added charge status and more LED control
2023-04-02 Add an exported schematic so people don't need to download and check
    [rusty-tracker.kicad_sch]
2023-04-04 MFPNs added
    [rusty-tracker.kicad_sch]
2023-04-23 Fix delay in PWM setting, fade from red to green for battery voltage
    [bsp.rs]
2023-04-24 Testing battery
2023-04-25 Make printing better, add socket closing on startup
